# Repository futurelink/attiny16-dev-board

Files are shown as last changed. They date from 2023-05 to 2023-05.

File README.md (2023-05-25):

## Small ATTiny1616/3216 development board with built-in RS-485/USB

This board was designed to work with new AVR chips that were based on good old architecture.
These chips have one undisputable feature - they are in tiny packages (VQFN-20 is 4x4mm) 
and they are extremely cheap but can run at 20MHz and have a full bunch of peripheral inside.

I also placed MAX3485 to support RS-485 line which can be switched back to CH340G to connect it
via USB (or even both can be disconnected if not needed).

A few images below:
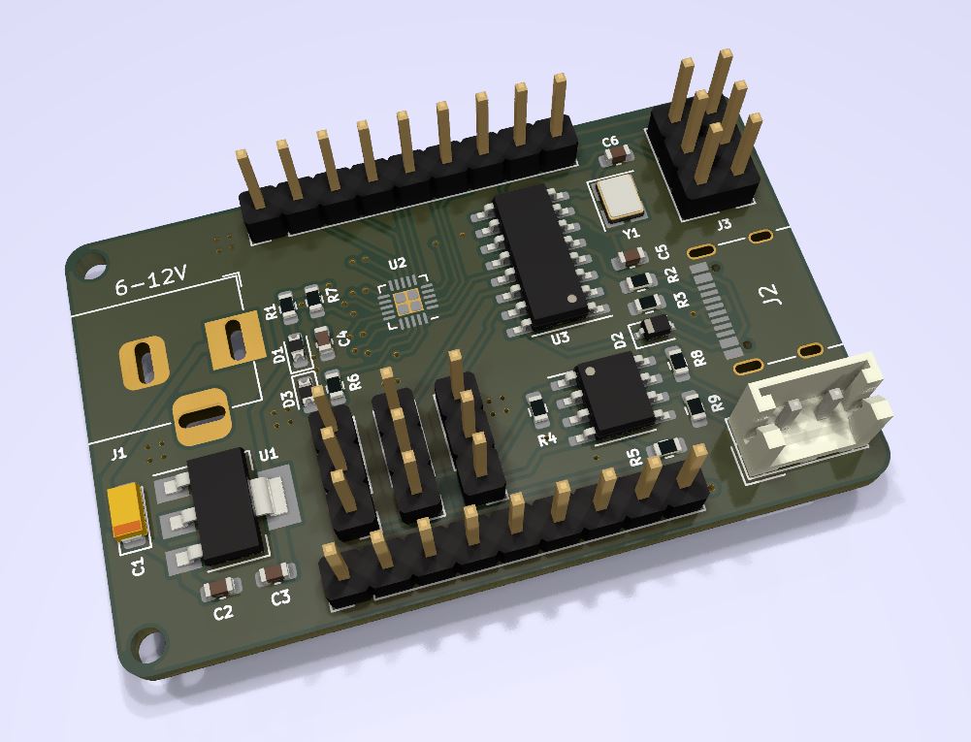
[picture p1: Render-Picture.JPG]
Render


Dimansions are here:
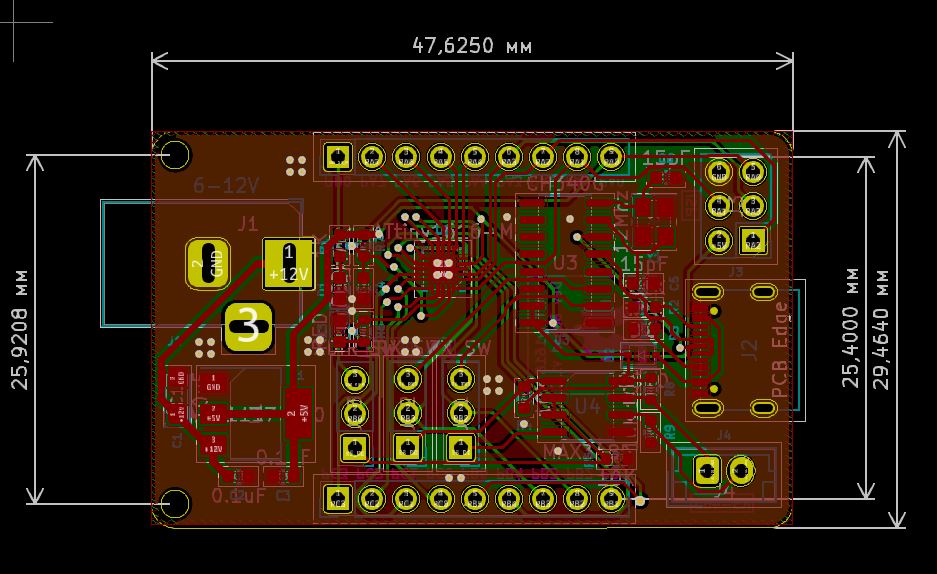
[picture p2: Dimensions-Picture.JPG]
Dimensions


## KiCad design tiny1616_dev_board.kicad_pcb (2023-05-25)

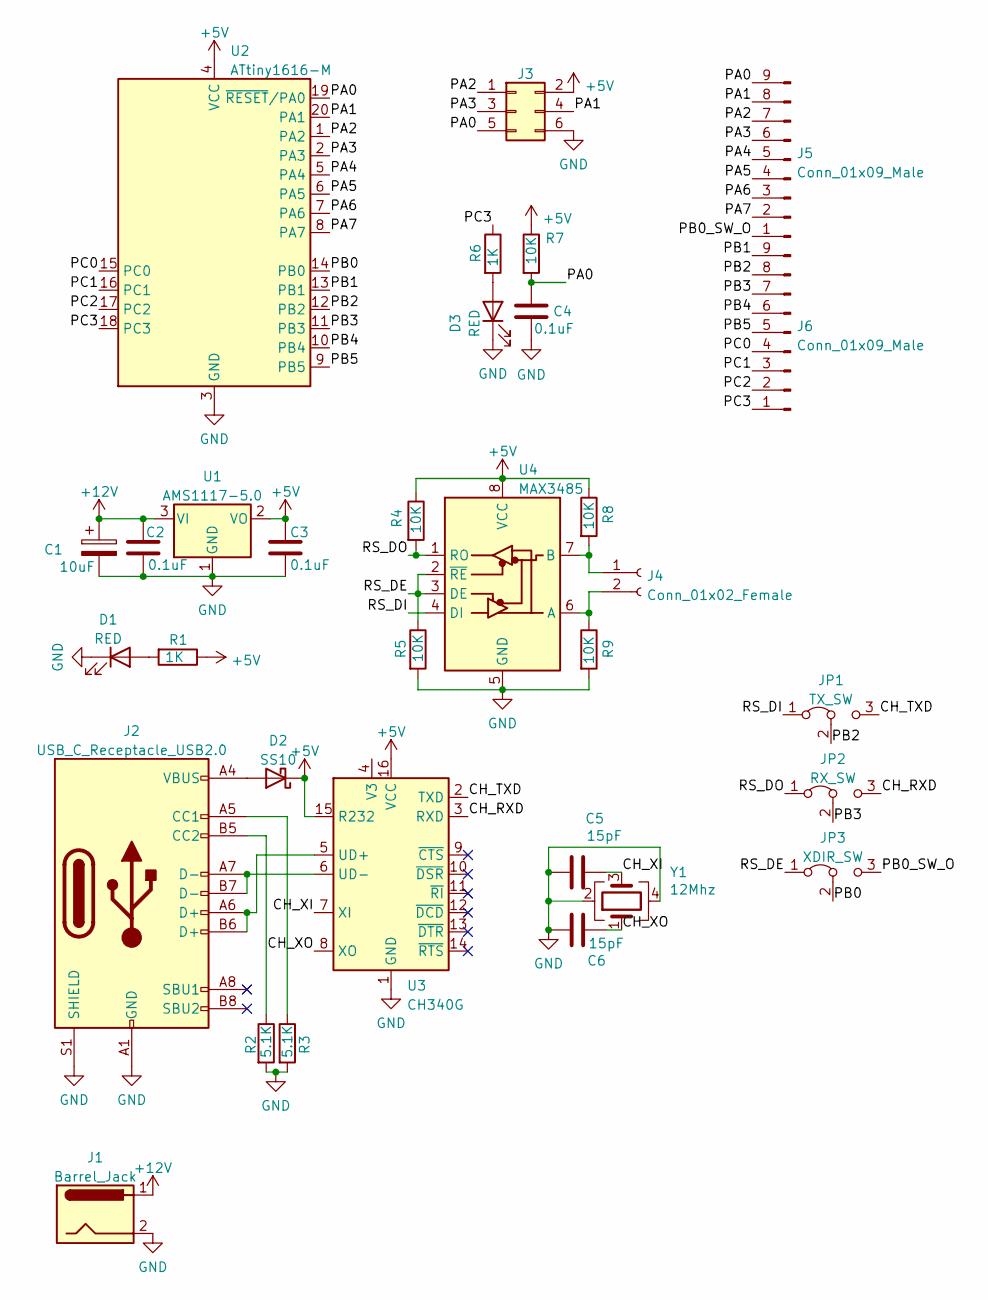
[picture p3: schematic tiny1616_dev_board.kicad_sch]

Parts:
C1: 10uF; CP_EIA-3216-10_Kemet-I
C2, C3, C4: 0.1uF; C_0603_1608Metric
C5, C6: 15pF; C_0603_1608Metric
D1, D3: RED; D_0603_1608Metric
D2: SS10; D_SOD-323
J1: Barrel_Jack; BarrelJack_Horizontal
J2: USB_C_Receptacle_USB2.0; USB_C_Receptacle_Palconn_UTC16-G
J3: Conn_02x03_Odd_Even; PinHeader_2x03_P2.54mm_Vertical
J4: Conn_01x02_Female; JST_EH_B2B-EH-A_1x02_P2.50mm_Vertical
J5, J6: Conn_01x09_Male; PinHeader_1x09_P2.54mm_Vertical
JP1: TX_SW; PinHeader_1x03_P2.54mm_Vertical
JP2: RX_SW; PinHeader_1x03_P2.54mm_Vertical
JP3: XDIR_SW; PinHeader_1x03_P2.54mm_Vertical
R1, R6: 1K; R_0603_1608Metric
R2, R3: 5.1K; R_0603_1608Metric
R4, R5, R7, R8, R9: 10K; R_0603_1608Metric
U1: AMS1117-5.0; SOT-223-3_TabPin2
U2: ATtiny1616-M; VQFN-20-1EP_3x3mm_P0.4mm_EP1.7x1.7mm
U3: CH340G; SOIC-16_3.9x9.9mm_P1.27mm
U4: MAX3485; SOIC-8_3.9x4.9mm_P1.27mm
Y1: 12Mhz; Crystal_SMD_3225-4Pin_3.2x2.5mm

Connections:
+5V: C3.1, D2.1 (K), J3.2, R1.1, R4.1, R7.1, R8.1, U1.2 (VO), U2.4 (VCC), U3.15 (R232), U3.16 (VCC), U4.8 (VCC)
+12V: C1.1, C2.1, J1.1, U1.3 (VI)
/CH_RXD: JP2.3 (B), U3.3 (RXD)
/CH_TXD: JP1.3 (B), U3.2 (TXD)
/CH_XI: C5.2, U3.7 (XI), Y1.3
/CH_XO: C6.2, U3.8 (XO), Y1.1
/PA0: C4.1, J3.5, J5.9, R7.2, U2.19 (~RESET/PA0)
/PA1: J3.4, J5.8, U2.20 (PA1)
/PA2: J3.1, J5.7, U2.1 (PA2)
/PA3: J3.3, J5.6, U2.2 (PA3)
/PA4: J5.5, U2.5 (PA4)
/PA5: J5.4, U2.6 (PA5)
/PA6: J5.3, U2.7 (PA6)
/PA7: J5.2, U2.8 (PA7)
/PB0: JP3.2 (C), U2.14 (PB0)
/PB0_SW_O: J5.1, JP3.3 (B)
/PB1: J6.9, U2.13 (PB1)
/PB2: J6.8, JP1.2 (C), U2.12 (PB2)
/PB3: J6.7, JP2.2 (C), U2.11 (PB3)
/PB4: J6.6, U2.10 (PB4)
/PB5: J6.5, U2.9 (PB5)
/PC0: J6.4, U2.15 (PC0)
/PC1: J6.3, U2.16 (PC1)
/PC2: J6.2, U2.17 (PC2)
/PC3: J6.1, R6.1, U2.18 (PC3)
/RS_DE: JP3.1 (A), R5.1, U4.2 (~RE), U4.3 (DE)
/RS_DI: JP1.1 (A), U4.4 (DI)
/RS_DO: JP2.1 (A), R4.2, U4.1 (RO)
GND: C1.2, C2.2, C3.2, C4.2, C5.1, C6.1, D1.1 (K), D3.1 (K), J1.2, J2.A1 (GND), J2.A12 (GND), J2.B1 (GND), J2.B12 (GND), J2.S1 (SHIELD), J3.6, R2.2, R3.2, R5.2, R9.2, U1.1 (GND), U2.3 (GND), U2.21 (GND), U3.1 (GND), U4.5 (GND), Y1.2, Y1.4
unnamed: D1.2 (A), R1.2
unnamed: D2.2 (A), J2.A4 (VBUS), J2.A9 (VBUS), J2.B4 (VBUS), J2.B9 (VBUS)
unnamed: D3.2 (A), R6.2
unnamed: J2.A5 (CC1), R3.1
unnamed: J2.A6 (D+), J2.B6 (D+), U3.5 (UD+)
unnamed: J2.A7 (D-), J2.B7 (D-), U3.6 (UD-)
unnamed: J2.B5 (CC2), R2.1
unnamed: J4.1, R8.2, U4.7 (B)
unnamed: J4.2, R9.1, U4.6 (A)

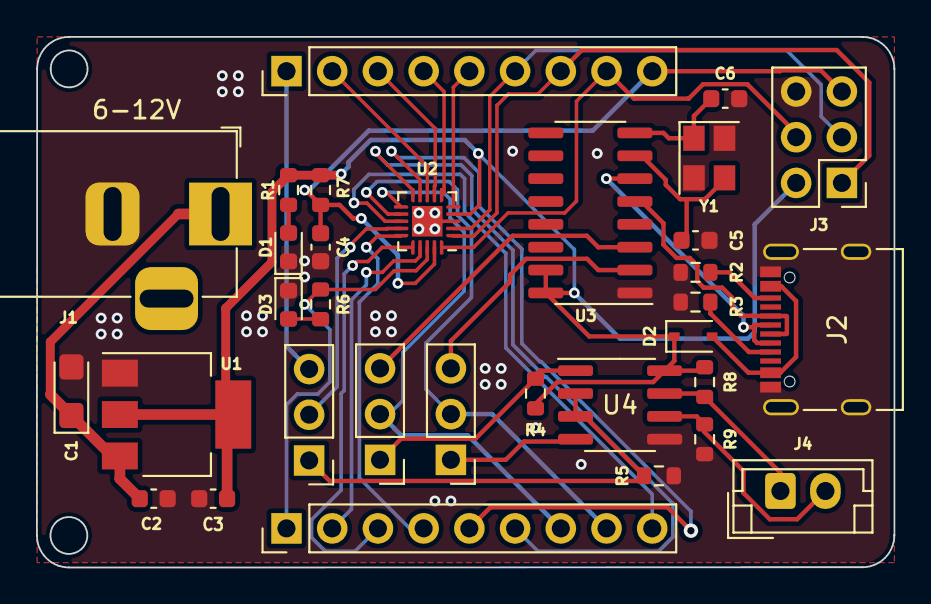
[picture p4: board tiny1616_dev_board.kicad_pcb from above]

Board: 2 copper layers, 47.6 x 29.5 mm, 32 parts (0 on the bottom side), 38 nets.
